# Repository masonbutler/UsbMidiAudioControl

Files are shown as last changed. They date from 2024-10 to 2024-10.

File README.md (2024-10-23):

# UsbMidiAudioControl
A personal project to provide basic MIDI controls over USB to control the Reaper DAW (Digital Audio Workstation). The code is all basically baremetal (But I wrote a small layer I wrote over some of the peripherals to make them easier to deal with. It's pretty transparent in how it works).

I bought some cheap RGB LEDs from AliExpress that were labeled as WS2812B-2020, so I figured why not make a project out of them that would be useful for myself. Unfortunately, there was no datasheet and the LEDs seem to be a bit glitchy with 3.3V (where a regular WS2812B is not). To solve this, you can use a level converter capable, or run the board output into a single WS2812B regular size LED since it corrects the expected signal and removes the glitching.

I decided to go with 4 channels, providing 1 fader (to control volume) and 2 buttons per channel. 

MixerUIBoard

This was also a great learning experience to bring up a USB device since I've never actually coded USB stuff low level and I've never dug into the descriptors for audio/MIDI devices. Safe to say, I learned a lot!  

## How does it work?

- Plug it in to the computer's USB port
- Open Reaper
- Select the device as a MIDI device (Device name: DAW Control)
- Enable MIDI input from device by right clicking the device and pressing "Enable Input"


- Assign the actions in the Actions tab of the program. I assigned the fader to the volume (0-127 since it is MIDI), and one button to MUTE and one button to RECORD.



## Technical stuff
The project uses an ATSAM L21 Explained Pro Devboard. Each linear fader goes into an ADC channel on the devboard, based upon tests the actual ADC value conversion has a range of 32-4080. The buttons are handled by a shift register that reads in the data over a SPI bus. The LED data is converted to a binary stream to provide the correct data format for a WS2812B LED then output over SPI.

## Physical Connections

PA22: UART TX

PA23: UART RX

PA9: Shift Reg Clock (SPI Clock)

PA10: Shift Reg SS (SPI SS)

PA11: Shift Reg Data In (SPI MISO)

PA16: LED Data Output (SPI MOSI)

PA4: Fader 1 (ADC Channel 4)

PA5: Fader 2 (ADC Channel 5)

PA6: Fader 3 (ADC Channel 6)

PA7: Fader 4 (ADC Channel 7)

## Compiling
Download Microchip Studio (Atmel Studio) 7.0.2594
Open project file from repo

## PCB


A 4 layer (pretty simple) board. It was same price as 2 layer at JLCPCB, so why not? I decided to give the LEDs their own power plane because the reviews of the LEDs complained about: thermal issues, current draw, and issues running of 3.3V instead of 5V. It was easier to track power (3.3V for anything else connected to the devboard). 

It's has purple soldermask and is pretty. 

## Dumb things I did
I did a few dumb things doing this:

I used LEDs ordered off Aliexpress expecting no real problems...ha ha ha.

I put the faders on upside down so I had to correct it in software. 0% is actually the highest value of the fader, while 100% is the lowest value. 

I soldered all of the components on this by hand (56 LEDs and 56 caps + headers + other components) because I didn't order a stencil when I ordered the PCBs (don't submit an order late at night).

I ordered logarithmic faders without realizing it because I ordered stuff at night. I spent 1 week wondering why my fader was giving me bad values on my ADC before I tried the ADC on a different devobard then realized...ugh.

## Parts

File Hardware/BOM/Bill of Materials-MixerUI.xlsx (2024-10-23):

Comment | Description | Designator | Footprint | LibRef | Quantity
10uF | Chip capacitors | C1 | 0603_C | 0603 10uF (106) 10% 10V | 1
4.7uF | Chip capacitors | C2, C3, C4, C5, C6, C7, C8, C9, C10, C11, C12, C13, C14, C15, C16, C17, C18, C19, C20, C21, C22, C23, C24, C25, C26, C27, C28, C29, C30, C31, C32, C33, C34, C35, C36, C37, C38, C39, C40, C41, C42, C43, C44, C45, C46, C47, C48, C49, C50, C51, C52, C53, C54, C55, C56, C57 | 0603_C | 0603 4.7uF (475) 10% 16V | 56
WS2812B-2020 | SMD,2x2mm RGB LEDs(Built-in IC) ROHS | D1, D2, D3, D4, D5, D6, D7, D8, D9, D10, D11, D12, D13, D14, D15, D16, D17, D18, D19, D20, D21, D22, D23, D24, D25, D26, D27, D28, D29, D30, D31, D32, D33, D34, D35, D36, D37, D38, D39, D40, D41, D42, D43, D44, D45, D46, D47, D48, D49, D50, D51, D52, D53, D54, D55, D56 | LED_WS2812-2020 | WS2812B-2020 | 56
1x10 HDR | Conn Unshrouded Header HDR 10 POS 2.54mm Solder ST Thru-Hole Bag | J1 | Hdr_Male_1x10_2.54mm | 69190-410HLF | 1
HDR 1x3 | BERGSTIK II .100" SR STRAIGHT | J2 | Hdr_1x3_2.54mm | 68000-103HLF | 1
0Ω | Chip resistor | R1, R2, R3, R4 | 0805_R | 0805 0R (0R0) 1% | 4
4.7KΩ | Chip resistor | R5, R6, R7, R8, R9, R10, R11, R12 | 0805_R | 0805 4.7K (4701) 1% | 8
1825910-6 | SWITCH TACTILE SPST-NO 0.05A 24V | SW1, SW2, SW3, SW4, SW5, SW6, SW7, SW8 | 1825910-6 | 1825910-6 | 8
74HC165D | 74系列逻辑芯片 | U1 | SOIC-16_150mil | 74HC165D_[C5613] | 1
SLIDE POT | 10 kOhms 0.125W, 1/8W Through Hole Slide Potentiometer Top Adjustment Type | VR1, VR2, VR3, VR4 | PTA6043-2015DPB103 | PTA6043-2015DPB103 | 4

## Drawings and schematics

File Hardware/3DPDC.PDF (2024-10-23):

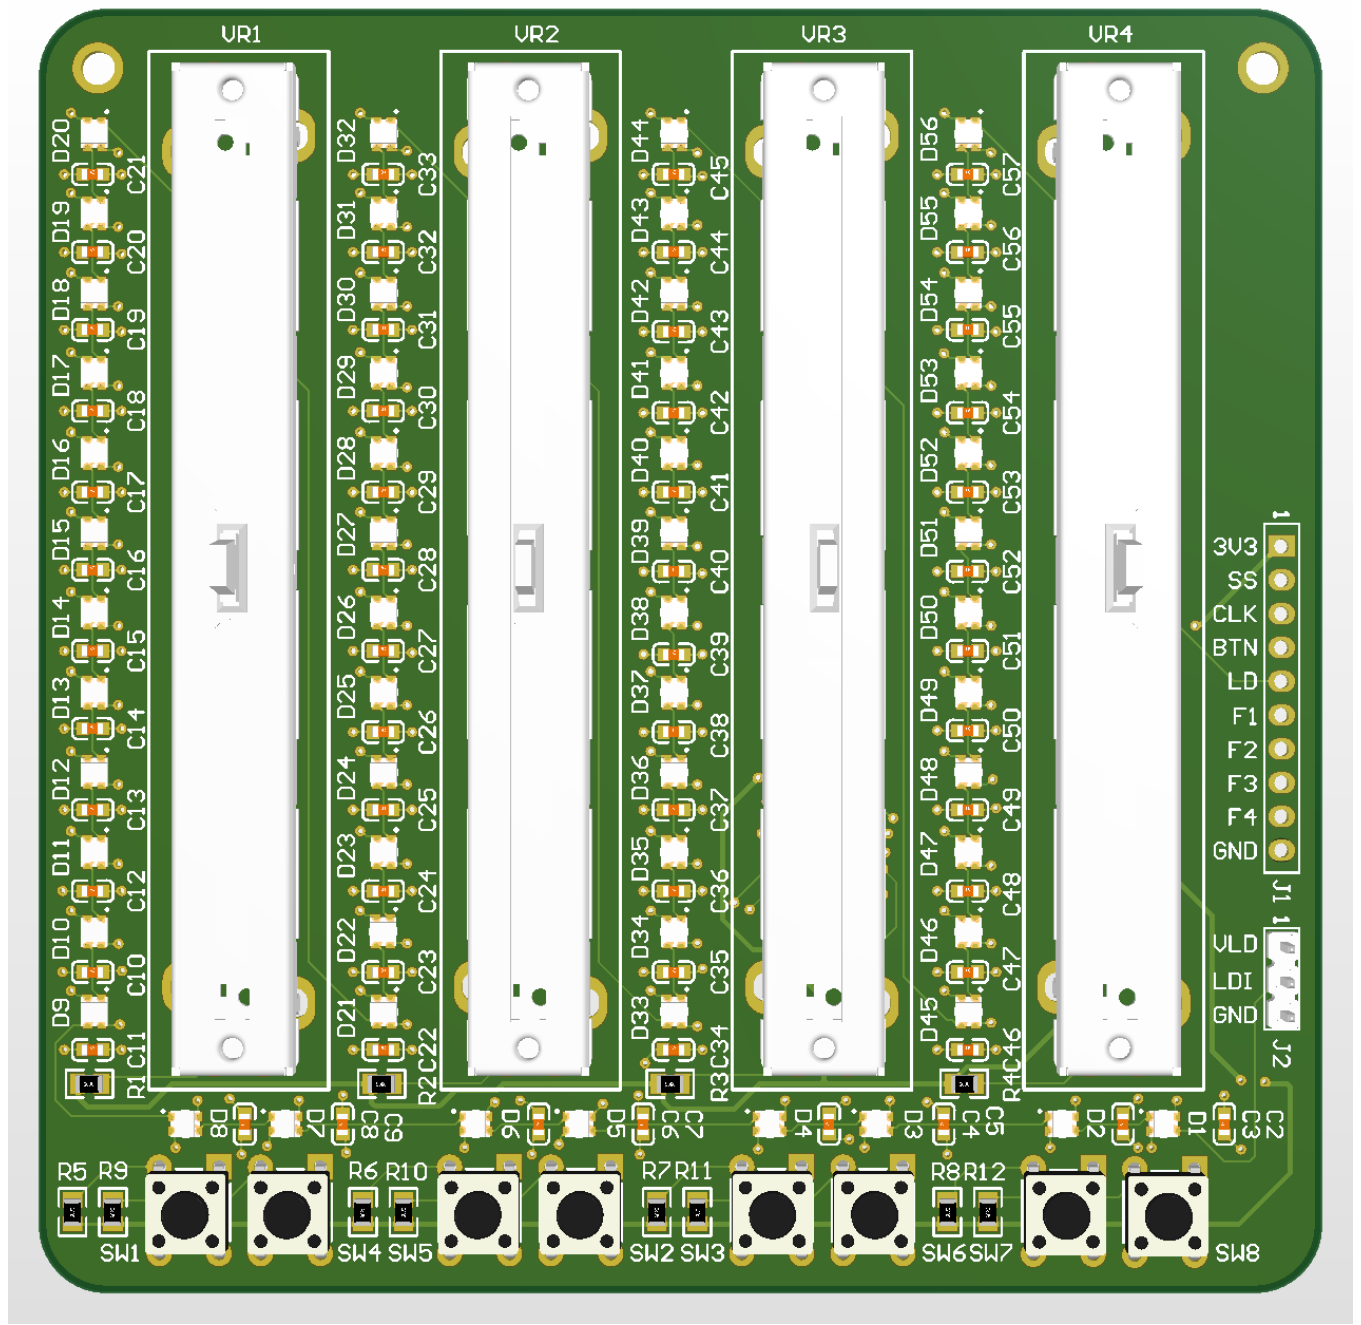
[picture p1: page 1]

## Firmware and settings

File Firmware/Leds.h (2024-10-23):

#ifndef LEDS_H_
#define LEDS_H_

#define NUM_LEDS	56U

#define NUM_LEDS_PER_FADER	12

#define DEFAULT_COLOUR_ON	{0, 0, 15}
#define DEFAULT_COLOUR_OFF	{15, 0, 15}

typedef enum {
	LED_NUM_START = 0,
	LED_NUM_CHAN4_SOLO = 0,
	LED_NUM_CHAN4_MUTE,
	LED_NUM_CHAN3_SOLO,
	LED_NUM_CHAN3_MUTE,
	LED_NUM_CHAN2_SOLO,
	LED_NUM_CHAN2_MUTE,
	LED_NUM_CHAN1_SOLO,
	LED_NUM_CHAN1_MUTE,
	
	LED_NUM_FADER1_0,  //8
	LED_NUM_FADER1_1,
	LED_NUM_FADER1_2,
	LED_NUM_FADER1_3,
	LED_NUM_FADER1_4,
	LED_NUM_FADER1_5,
	LED_NUM_FADER1_6,
	LED_NUM_FADER1_7,
	LED_NUM_FADER1_8,
	LED_NUM_FADER1_9,
	LED_NUM_FADER1_10,
	LED_NUM_FADER1_11, // 19
	
	LED_NUM_FADER2_0, // 20
	LED_NUM_FADER2_1,
	LED_NUM_FADER2_2,
	LED_NUM_FADER2_3,
	LED_NUM_FADER2_4,
	LED_NUM_FADER2_5,
	LED_NUM_FADER2_6,
	LED_NUM_FADER2_7,
	LED_NUM_FADER2_8,
	LED_NUM_FADER2_9,
	LED_NUM_FADER2_10,
	LED_NUM_FADER2_11, // 31
	
	LED_NUM_FADER3_0, //32
	LED_NUM_FADER3_1,
	LED_NUM_FADER3_2,
	LED_NUM_FADER3_3,
	LED_NUM_FADER3_4,
	LED_NUM_FADER3_5,
	LED_NUM_FADER3_6,
	LED_NUM_FADER3_7,
	LED_NUM_FADER3_8,
	LED_NUM_FADER3_9,
	LED_NUM_FADER3_10,
	LED_NUM_FADER3_11, // 43
	
	LED_NUM_FADER4_0, // 44
	LED_NUM_FADER4_1,
	LED_NUM_FADER4_2,
	LED_NUM_FADER4_3,
	LED_NUM_FADER4_4,
	LED_NUM_FADER4_5,
	LED_NUM_FADER4_6,
	LED_NUM_FADER4_7,
	LED_NUM_FADER4_8,
	LED_NUM_FADER4_9,
	LED_NUM_FADER4_10,
	LED_NUM_FADER4_11, // 55
	
	LED_NUM_END,
} LED_NUM;

typedef enum {
	LED_STATE_OFF = 0,
	LED_STATE_ON
} LED_STATE;

typedef struct {
	uint8_t r;
	uint8_t g;
	uint8_t b;
} sRGBColour;

typedef struct {
	LED_STATE ledState;
	sRGBColour onColour;
	sRGBColour offColour;
} sLedData;

void InitLeds();
void UpdateLedColourDataAll();
void UpdateLedColourData(LED_NUM ledNum);
void SendLedData();

void SetLed(LED_NUM ledNum, LED_STATE state, sRGBColour onCol, sRGBColour offCol);
void SetLedColour1(LED_NUM ledNum, sRGBColour onCol);
void SetLedColour2(LED_NUM ledNum, sRGBColour offCol);
void SetLedState(LED_NUM ledNum, LED_STATE state);


LED_STATE GetLedState(LED_NUM ledNum);

#endif /* LEDS_H_ */

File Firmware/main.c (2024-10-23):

#include "sam.h"
#include "System.h"
#include "SysTick.h"
#include "DawController.h"

int main(void)
{
    SystemClock48MhzInit();
	__enable_irq();
	// Tick every 1000ms / 100 =  10 ms
	SysTickInit(100);
	SysTickStart();
	
	DawControllerInit();

    while (1) 
    {	
		DawControllerProcessInput();
		DawControllerDraw();
	}
}

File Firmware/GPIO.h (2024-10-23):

#ifndef GPIO_H_
#define GPIO_H_
#include <sam.h>

typedef enum {
	GPIO_PORT_A = 0,	/**< Port A */
	GPIO_PORT_B,		/**< Port B */
} GPIO_PORT_NAME;


typedef enum {
	GPIO_PIN_MODE_INPUT = 1,		/**< Input mode */
	GPIO_PIN_MODE_OUTPUT = 2,		/**< Output mode */
	GPIO_PIN_MODE_MUXED = 4,		/**< Mux mode */
} GPIO_PIN_MODE;

typedef enum {
	GPIO_MUX_SETTING_NONE = 0,
	GPIO_MUX_SETTING_A = 0,
	GPIO_MUX_SETTING_B,
	GPIO_MUX_SETTING_C,
	GPIO_MUX_SETTING_D,
	GPIO_MUX_SETTING_E,
	GPIO_MUX_SETTING_F,
	GPIO_MUX_SETTING_G,
	GPIO_MUX_SETTING_H,
	GPIO_MUX_SETTING_I,
} GPIO_MUX_SETTING;

// Only available when pin set to INPUT
typedef enum {
	GPIO_PULLUPDOWN_NONE = 0,		/**< No pull-up or pull-down active */
	GPIO_PULLUPDOWN_PULLUP = 1,		/**< Pull-up active */
	GPIO_PULLUPDOWN_PULLDOWN = 2,	/**< Pull-down active */
} GPIO_PULLUPDOWN ;

/**
* A structure of a GPIO pin, its configuration settings
*/
typedef struct {
	uint8_t port : 1;					/**< Letter of the port the pin is on */
	uint8_t pinNum : 5;					/**< Pin number on the port, i.e PB9, number is 9, 0-31 */
	uint8_t mode : 3;					/**< Pin output, input, or alternate function */
	uint8_t pullUpDown: 2;				/**< Pin pull-up or pull-down configuration */
	uint8_t muxSetting: 4;				/**< The alternate function number when MUX is set (see MCU datasheet) */
} sGPIOPin;

/*!
* Initialize a GPIO pin
* @param[in] pin The pointer to the GPIOPin struct defining the pin
* @return The result of the action (success or error)
*/
void GPIOPinInit(sGPIOPin *pin);

/*!
* Set a pin to HIGH (logic 1)
* @param[in] pin The pointer to the GPIOPin struct defining the pin
*/
void GPIOPinSetPin(sGPIOPin *pin);

/*!
* Clear a pin to LOW (logic 0)
* @param[in] pin The pointer to the GPIOPin struct defining the pin
*/
void GPIOPinClearPin(sGPIOPin *pin);

/*!
* Toggle the value of a pin
* @param[in] pin The pointer to the GPIOPin struct defining the pin
*/
void GPIOPinTogglePin(sGPIOPin *pin);

/*!
* Read the value of a pin and return it
* @param[in] pin The pointer to the GPIOPin struct defining the pin
*/
uint8_t GPIOReadPin(sGPIOPin *pin);

#endif /* GPIO_H_ */

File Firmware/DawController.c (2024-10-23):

#include <sam.h>
#include <stdlib.h>
#include "GPIO.h"
#include "UART.h"
#include "ADC.h"
#include "SPI.h"
#include "USB/UsbDevice.h"
#include "USB/Standard//UsbMidi.h"
#include "MidiMessages.h"
#include "Buttons.h"
#include "Faders.h"
#include "Leds.h"

#define MIDI_OUT_EP	(1)
#define NUM_BUTTONS	(8)
#define NUM_FADERS	(4)


sGPIOPin uartTXPin = {
	GPIO_PORT_A,
	22,
	GPIO_PIN_MODE_OUTPUT | GPIO_PIN_MODE_MUXED,
	GPIO_PULLUPDOWN_NONE,
	GPIO_MUX_SETTING_C
};

sGPIOPin uartRXPin = {
	GPIO_PORT_A,
	23,
	GPIO_PIN_MODE_INPUT | GPIO_PIN_MODE_MUXED,
	GPIO_PULLUPDOWN_NONE,
	GPIO_MUX_SETTING_C
};

sUARTDevice uart3 = {
	SERCOM3,
	UART_RX_PAD1,
	UART_TX_PAD_CONFIG0,
	UART_PARITY_EVEN,
	UART_STOPBITS_NUM_1,
	UART_CHARSIZE_8BITS,
	115200,
	UART_TRANSCEIVER_ENABLE_TX,
};

sGPIOPin spiBtnShiftRegClk = {
	GPIO_PORT_A,
	9,
	GPIO_PIN_MODE_OUTPUT | GPIO_PIN_MODE_MUXED,
	GPIO_PULLUPDOWN_NONE,
	GPIO_MUX_SETTING_C
};

sGPIOPin spiBtnShiftRegSS = {
	GPIO_PORT_A,
	10,
	GPIO_PIN_MODE_OUTPUT,
	GPIO_PULLUPDOWN_NONE,
	GPIO_MUX_SETTING_NONE,
};

sGPIOPin spiBtnShiftRegMISO = {
	GPIO_PORT_A,
	11,
	GPIO_PIN_MODE_INPUT | GPIO_PIN_MODE_MUXED,
	GPIO_PULLUPDOWN_NONE,
	GPIO_MUX_SETTING_C
};

sSPIDevice spiBtnShiftRegDevice = {
	SERCOM0,
	&spiBtnShiftRegSS,
	2000000U,
	SPI_OPERATING_MODE_HOST,
	SPI_DATA_ORDER_MSB,
	SPI_CLOCK_POL_IDLE_LOW,
	SPI_CLOCK_PHA_SAMPLE_LEADING,
	SPI_DATAIN_PAD3,
	SPI_DATAOUT_PAD_CONFIG0,
	SPI_DUPLEX_FULL,
};

sGPIOPin ledData = {
	GPIO_PORT_A,
	16,
	GPIO_PIN_MODE_OUTPUT | GPIO_PIN_MODE_MUXED,
	GPIO_PULLUPDOWN_NONE,
	GPIO_MUX_SETTING_C
};

sSPIDevice spiLeds = {
	SERCOM1,
	NULL,
	3000000U,
	SPI_OPERATING_MODE_HOST,
	SPI_DATA_ORDER_MSB,
	SPI_CLOCK_POL_IDLE_LOW,
	SPI_CLOCK_PHA_SAMPLE_LEADING,
	SPI_DATAIN_PAD3,
	SPI_DATAOUT_PAD_CONFIG0,
	SPI_DUPLEX_FULL,
};

sGPIOPin adcFader1 = {
	GPIO_PORT_A,
	4,
	GPIO_PIN_MODE_INPUT | GPIO_PIN_MODE_MUXED,
	GPIO_PULLUPDOWN_NONE,
	GPIO_MUX_SETTING_B
};

sGPIOPin adcFader2 = {
	GPIO_PORT_A,
	5,
	GPIO_PIN_MODE_INPUT | GPIO_PIN_MODE_MUXED,
	GPIO_PULLUPDOWN_NONE,
	GPIO_MUX_SETTING_B
};

sGPIOPin adcFader3 = {
	GPIO_PORT_A,
	6,
	GPIO_PIN_MODE_INPUT | GPIO_PIN_MODE_MUXED,
	GPIO_PULLUPDOWN_NONE,
	GPIO_MUX_SETTING_B
};

sGPIOPin adcFader4 = {
	GPIO_PORT_A,
	7,
	GPIO_PIN_MODE_INPUT | GPIO_PIN_MODE_MUXED,
	GPIO_PULLUPDOWN_NONE,
	GPIO_MUX_SETTING_B
};

sADCDevice adcDevice = {
	ADC,
	ADC_PRESCALER_DIV64,
	ADC_REF_SRC_INTVCC2,
	ADC_INPUTCTRL_MUXPOS_AIN8,
	ADC_NEGREF_SRC_GND,
	ADC_REFCOMP_ENABLED,
	ADC_RESOLUTION_12BIT,
	ADC_DIGITAL_CORR_ENABLED,
	ADC_RUN_MODE_SINGLE,
	0x80,
	ADC_SAMPLES_AVG_NUM_64
};

sGPIOPin UsbDM = {
	GPIO_PORT_A,
	24,
	GPIO_PIN_MODE_MUXED,
	GPIO_PULLUPDOWN_NONE,
	GPIO_MUX_SETTING_G
};

sGPIOPin UsbDP = {
	GPIO_PORT_A,
	25,
	GPIO_PIN_MODE_MUXED,
	GPIO_PULLUPDOWN_NONE,
	GPIO_MUX_SETTING_G
};

sUsbDevice usbDevice = {
	USB,
	USB_SPEED_FULLSPEED
};

static sButton buttons[8];
static sFader faders[4];

static void ButtonCallback(uint8_t buttonId, uint8_t buttonEvent);
static void FaderCallback(uint8_t faderId, uint8_t faderEvent, uint8_t value);

UsbMidiMessage midiData = { 0 };

void DawControllerInit()
{
	// Uart init
	GPIOPinInit(&uartTXPin);
	GPIOPinInit(&uartRXPin);
	UARTInit(&uart3, 3);
	
	// Button shift reg init
	GPIOPinInit(&spiBtnShiftRegSS);
	GPIOPinInit(&spiBtnShiftRegClk);
	GPIOPinInit(&spiBtnShiftRegMISO);
	SPIInit(&spiBtnShiftRegDevice, 0);
	
	// Leds init
	GPIOPinInit(&ledData);
	SPIInit(&spiLeds, 1);
	
	// ADC Faders init
	GPIOPinInit(&adcFader1);
	GPIOPinInit(&adcFader2);
	GPIOPinInit(&adcFader3);
	GPIOPinInit(&adcFader4);

	ADCInit(&adcDevice);

	UARTEnable(&uart3);
	SPIEnable(&spiLeds);
	SPIEnable(&spiBtnShiftRegDevice);
	ADCEnable(&adcDevice);
	
	GPIOPinInit(&UsbDM);
	GPIOPinInit(&UsbDP);
	UsbInit(&usbDevice);
	UsbEnable(&usbDevice);

	uint8_t btnNum = NUM_BUTTONS;
	for(int btn = 0; btn < NUM_BUTTONS; btn++)
	{	
		InitButton(&buttons[btn], --btnNum, &ButtonCallback);
	}
	
	for(int fader = 0; fader < NUM_FADERS; fader++)
	{
		InitFader(&faders[fader], fader, &FaderCallback);
	}
	
	InitLeds();
	UsbConnect(&usbDevice);
}

void DawControllerProcessInput()
{
	ProcessButtons(&spiBtnShiftRegDevice, buttons, NUM_BUTTONS, &uart3);
	
	for(int fader = 0; fader < NUM_FADERS; fader++)
	{
		ProcessFader(&adcDevice, &faders[fader], &uart3);
	}
}

void DawControllerDraw()
{
	// TODO: Switch to DMA
	SendLedData(&spiLeds);
}

static void ButtonCallback(uint8_t buttonId, uint8_t buttonEvent)
{
	if(buttonEvent == BUTTON_STATE_RELEASED)
	{
		uint8_t ledState = GetLedState(buttonId);
		if(ledState == LED_STATE_ON)
		{
			midiData.cableNum = 0;
			midiData.codeIndexNum = 0xB;
			midiData.data0 = MIDI_CC;
			midiData.data1 = buttonId + 14; // Button number
			midiData.data2 = 0x0; // Midi is data is 7bit, MSB is reserved

			UsbSend(&usbDevice, MIDI_OUT_EP, (uint8_t *) &midiData, sizeof(UsbMidiMessage));
			SetLedState(buttonId, LED_STATE_OFF);
		}
		else if(ledState == LED_STATE_OFF)
		{
			midiData.cableNum = 0;
			midiData.codeIndexNum = 0xB;
			midiData.data0 = MIDI_CC;
			midiData.data1 = buttonId + 14; // Button number
			midiData.data2 = 0x7F;
			
			UsbSend(&usbDevice, MIDI_OUT_EP, (uint8_t *) &midiData, sizeof(UsbMidiMessage));
			SetLedState(buttonId, LED_STATE_ON);
		}
	}
}

static void FaderCallback(uint8_t faderId, uint8_t faderEvent, uint8_t value)
{	
	if(faderEvent == FADER_EVENT_CHANGED)
	{
		switch(faderId)
		{
		case 0:
			{
				midiData.cableNum = 0;
				midiData.codeIndexNum = 0xB;
				midiData.data0 = MIDI_CC;
				midiData.data1 = faderId + 5;
				midiData.data2 = value;
				
				UsbSend(&usbDevice, MIDI_OUT_EP, (uint8_t *) &midiData, sizeof(UsbMidiMessage));
			}
			break;
		case 1:
		case 2:
		case 3:
		default:
			break;
		}
	}
}

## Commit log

2024-10-23 Base files. Fader1, Buttons, MIDI over USB working
2024-10-23 Fix LED colour sequence, removed unused test files
    [Leds.c]
2024-10-23 Updated readme with PCB info
2024-10-23 Hardware files
    [Bill of Materials-MixerUI.xlsx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]
